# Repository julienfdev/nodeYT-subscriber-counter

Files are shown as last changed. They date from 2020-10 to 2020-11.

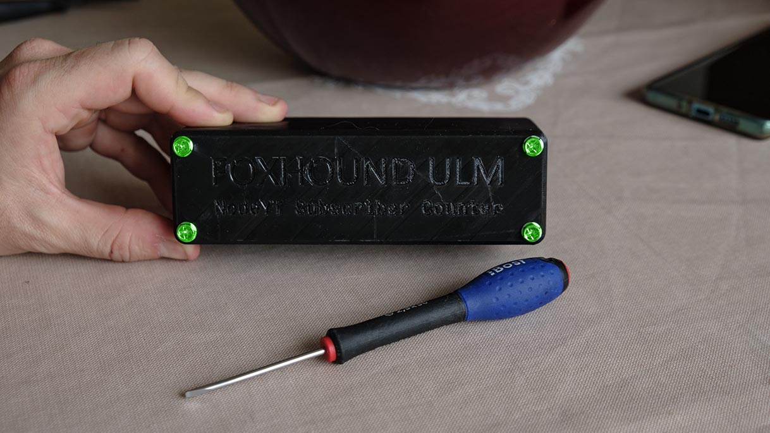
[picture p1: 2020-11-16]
img/howto-5.05f7cd65.jpg

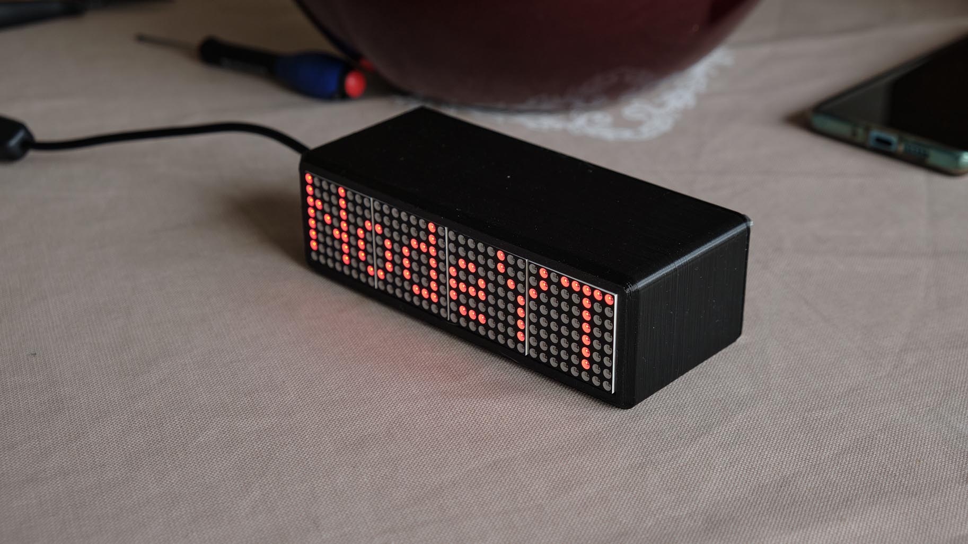
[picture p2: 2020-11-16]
img/howto-6.be0a37dc.jpg

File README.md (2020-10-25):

# NodeYT Subscriber Counter
## ESP8266 Version
A cheap ESP8266 - NodeMCU v3 subscriber counter - CC BY 4.0

See branch arduino-rpi for the Arduino / Raspberry Pi version (not maintained)

## Overview

The Node YT Subscriber Counter is a small and cheap LED Matrix YouTube counter based on a nodeMCU board (ESP8266) and a 8x32 MAX7219 LED Matrix.
As the name suggests... it counts YouTube subscribers

 ## Bill Of Material

### Mandatory
 - NodeMCU V3 ESP8266 Developement board - __7.79€__ https://amzn.to/31ySlPQ
 - 8x32 MAX7219 LED Matrix - __9.99€__ https://amzn.to/2HclQzS 
 - Arduino IDE 1.8+

### Optional
 - A 3D printer to print the case
 - 8x H5x6mm hex posts
 - 8x M3x8mm Socket Head Cap Screws
 - 4x 3.2x5mm Hex or Phillips screws (backplate fixation)
 - 5x 2.54mm (0.1" in Yankee units) male pin headers

__*Total BOM : 17.8€ + enclosure*__

## ESP8266 Configuration 

### Configuration and Upload
 - Clone the repository
 - Create a config.h file in ./esp8266, as following :

        #define MODE_SUBSCRIBERS 0

        String apiKey = "YOUR_YOUTUBE_API_KEY";
        String channelId = "YOUR_YOUTUBE_CHANNEL_ID";
        String ssid = "WIFI_SSID_TO_CONNECT_TO";
        String wifiPass = "WPA||WPA2__KEY";
        long refreshMillis = ;            // Refresh time in milliseconds
        int timezone = ; // Your Timezone eg : 1 for GMT+1 and -7 for GMT-7
        const char trustRoot[] PROGMEM = R"EOF(
                -----BEGIN CERTIFICATE-----
                THE_GOOGLE_API_CERTIFICATE
                -----END CERTIFICATE-----
                )EOF";
        // Caution, you must begin and end the String with R"EOF( )EOF" as shown;
        // To find the valid certificate just fetch anything at https://www.googleapis.com/ and click the lock next to the URL
        // Take the X509 Certificate and not SHA1 or SHA256 signature as they expires eventually

        String apiCall = String("https://www.googleapis.com/youtube/v3/channels?part=statistics&id=" + channelId + "&key=" + apiKey);

- Open the Arduino IDE and add the following source to the Additionnal Board Manager (Preferences)

        https://arduino.esp8266.com/stable/package_esp8266com_index.json

- Install the ESP8266 boards with the Board Manager
- Install the following libraries : 

        ArduinoJson // by Benoit Blanchon
        MD_Parola

- Select NodeMCU 1.0 and keep the default settings
- Open and upload the sketch to the board

### Remarks / Misc

__Boot sequence__

The NodeYT counter go through the following boot sequence : 
- Prints nodeYT during WiFi connection
- Synchronizes to NTP servers
- Prints the current local Time
- Fetches and print the subscriber count

__Serial debugger__

The ESP8266 opens a Serial at 115200 bauds, it sends various debug data :

- WiFi IP address
- Start / Response of HTTPS GET requests
- Current subscriber count or "same sub count" message
- Errors (to be improved)

Current soft watchdog implemementation assumes the animateDisplay() always eventually sends a true at the end of an animation. 

### Errors codes

Even if the serial provides detailed information about what's going on, one would find interesting to quick diagnose any problems. The displays thus prints various error codes depending on the issue : 

__WiFi related error codes__

- SSID : The SSID in config.h can't be reached
- Passwd : Wrong WPA||WPA2 Passkey

__API Related error codes__

- "HTTPS" : Can't establish https tunnel (verify your X509 certificate)
- "APIKey" : Bad Request code received from the YT API, most likely related to a bad API Private key
- "channel" : No channel exists with the ID provided in config.h
- err"xxx" : Generic error handler, displays the response code from the server

### WIP

- Clock Mode?
- Mode pushbutton (views-subs-clock)
- LED intensity potentiometer

## 3D printed case

### Hardware modifications :

A single mod needs to be done to the LED Matrix in order to fit into the RTM case (no mod if you're using the prototype one, but it's not advised as the RTM model is daaaamn slicker).

- Desolder the angled pin headers
- Solder the straight pin headers back, facing the side without any components (duh)

### Provided Files

The STL and Cura files provided assume a 20x123.5mm fixation pattern for the 8x32 LED Matrix

Disclamer about the prototype CATIA files : they are absolute shit as it's a revamp from the RPI+Arduino version.
RTM should be cleaner ^^

### Printing

Printing at 200/60°C with Geetech black PLA, 0.24mm layer height, tree support and faceplate ironing yields great results on an Ender3.

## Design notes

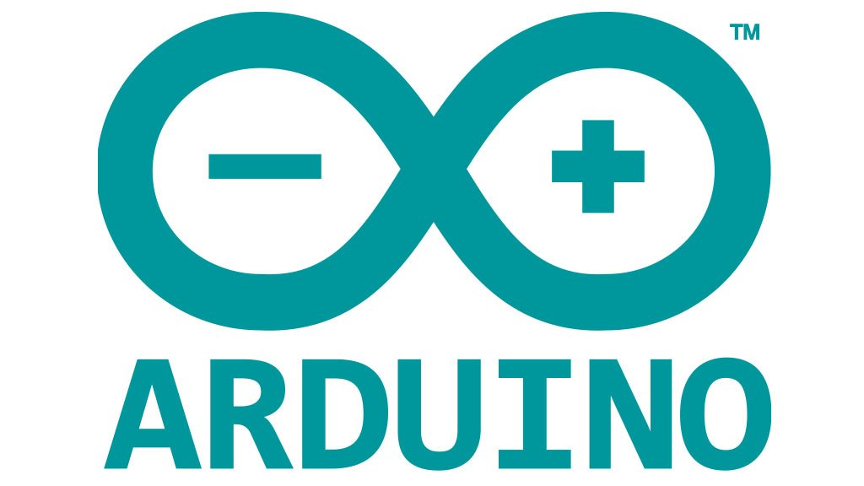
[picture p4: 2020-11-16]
img/card-0.86d80428.jpg

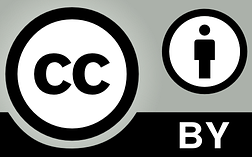
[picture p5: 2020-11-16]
img/cc-by.729ac44f.png

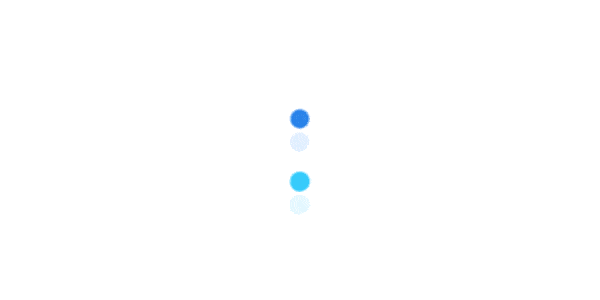
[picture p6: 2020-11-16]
img/spinner.845b3c8d.gif

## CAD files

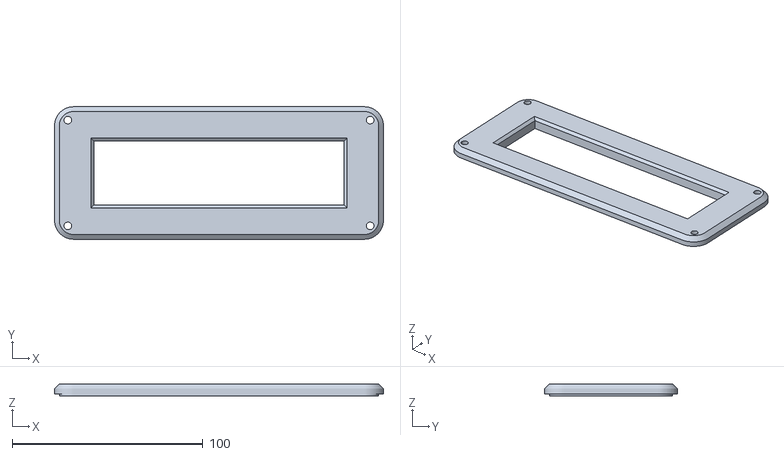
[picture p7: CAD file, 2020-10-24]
case/cura/stl/prototype/faceplate.stl
172.3 x 69.4 x 6.40

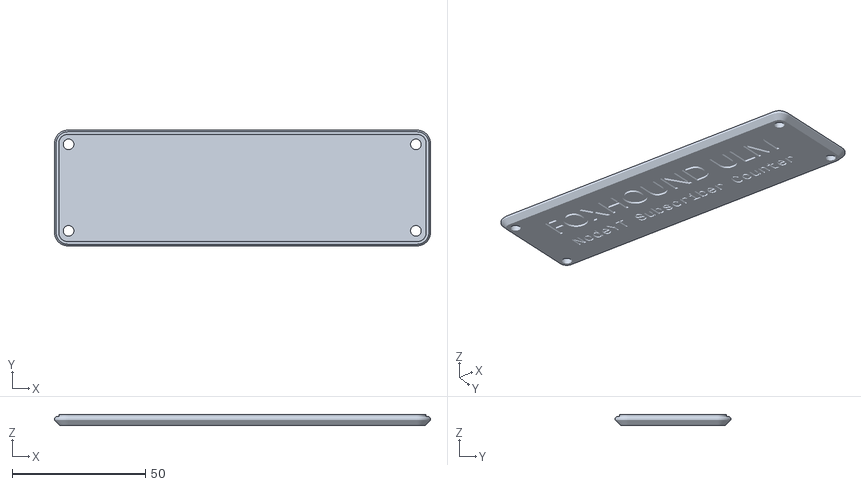
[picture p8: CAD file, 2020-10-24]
case/cura/stl/rtm/v2-backplate.stl
141.3 x 43.5 x 4.00

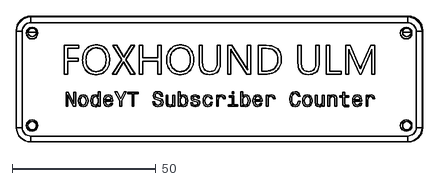
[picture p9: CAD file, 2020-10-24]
case/native/marking.dxf
141.5 x 43.8

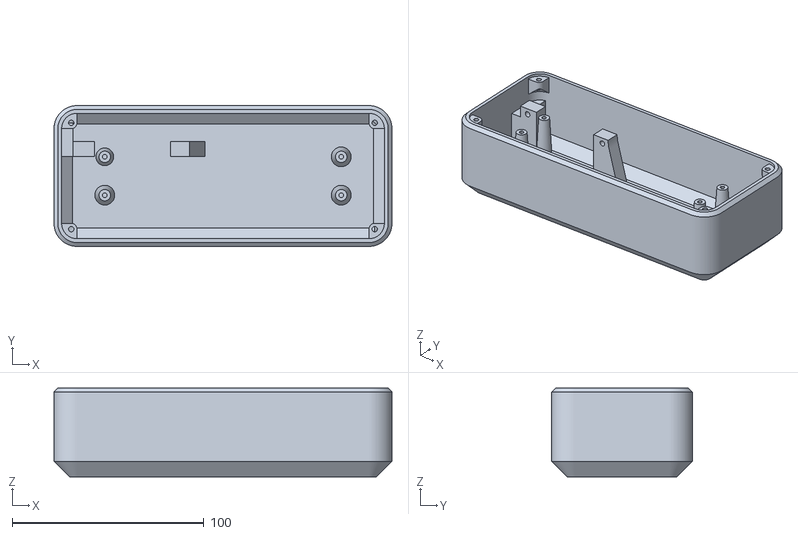
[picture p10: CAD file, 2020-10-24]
case/cura/stl/prototype/back-elmt.stl
176.3 x 73.4 x 46.2

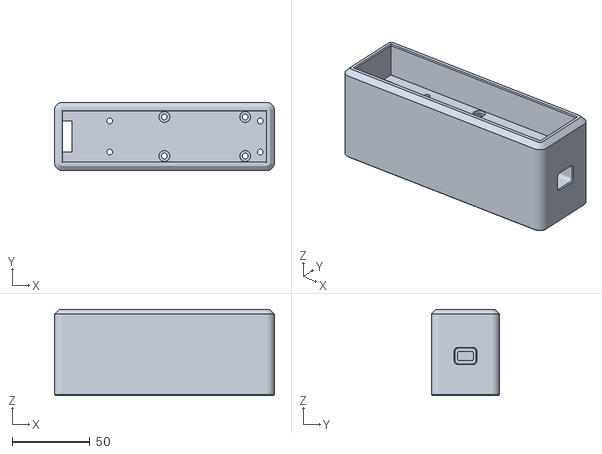
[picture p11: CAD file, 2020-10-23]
case/cura/stl/rtm/v2-case.stl
141.5 x 43.8 x 55.5

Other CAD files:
case/native/Part1.CATPart
case/native/backplate.CATPart
case/native/case-v2.CATPart
case/native/faceplate.CATPart
case/native/nodeYT-case.CATProduct

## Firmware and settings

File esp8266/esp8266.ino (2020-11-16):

// Networking
#include <ArduinoJson.h>
#include <ESP8266WiFi.h>
#include <ESP8266HTTPClient.h>
#include <WiFiClientSecureBearSSL.h>

// LED Matrix
#include <MD_Parola.h>
#include <MD_MAX72xx.h>
#include <SPI.h>
#define HARDWARE_TYPE MD_MAX72XX::FC16_HW
//#define MAX_DEVICES 1    //DEBUG
#define MAX_DEVICES 4
#define CLK_PIN   D5 // or SCK
#define DATA_PIN  D7 // or MOSI
#define CS_PIN    D8 // or SS

// Initializing the LED Matrix object with hardware SPI
MD_Parola P = MD_Parola(HARDWARE_TYPE, CS_PIN, MAX_DEVICES);

#include "config.h"

/*
   GLOBAL VARIABLES
*/
long subscriberCount = 0;
byte displayMode = MODE_SUBSCRIBERS;

// Creating an X509 Certificate based on the trustRoot signature in config.h
X509List cert(trustRoot);

// Creating the JSON Document Placeholder
const size_t capacity = JSON_ARRAY_SIZE(1) + JSON_OBJECT_SIZE(1) + 2 * JSON_OBJECT_SIZE(4) + JSON_OBJECT_SIZE(5) + 300;
DynamicJsonDocument doc(capacity);

void setup() {

  // Serial debugger
  Serial.begin(115200);
  Serial.println();

  // Setting up the display
  P.begin();
  P.setIntensity(1);
  P.setTextAlignment(PA_RIGHT);
  // Printing the welcome text
  P.displayText("NodeYT", PA_RIGHT, 50, 50, PA_SCROLL_RIGHT);
  // While the animation isn't finished
  while (!P.displayAnimate()) {
    ESP.wdtFeed(); // Feeding the Watchdog to avoid soft reset
  }


  // Initializing WiFi with SSID and provided in config file
  WiFi.begin(ssid, wifiPass);

  // Looping while not connected, need to be perfected to take errors into account ant print them
  while (WiFi.status() != WL_CONNECTED)
  {
    delay(500);
    Serial.print(".");
    wifiErrorHandler();
  }
  Serial.println();

  Serial.print("Connected, IP address: ");
  Serial.println(WiFi.localIP());
  Serial.println("");

  // Synchronising Time (GMT+1)
  configTime(timezone * 3600, 0, "pool.ntp.org", "time.nist.gov");
  // DST function to be done and recalled

  Serial.print("Waiting for NTP time sync: ");
  time_t now = time(nullptr);
  while (now < 8 * 3600 * 2) {
    delay(500);
    Serial.print(".");
    now = time(nullptr);
  }
  Serial.println("");
  struct tm timeinfo;
  struct tm timeLocal;
  gmtime_r(&now, &timeinfo);
  localtime_r(&now, &timeLocal);
  Serial.print("Zulu Time: ");
  Serial.print(asctime(&timeinfo));
  Serial.print("Local Time :");
  Serial.print(asctime(&timeLocal));

  // Printing local Time (DST to be implemented)
  String minutes = String(String(timeLocal.tm_min));
  Serial.println(minutes.length());
  if (!(minutes.length() > 1)) {
    minutes = String("0" + minutes);
  }
  String timeString = String(String("") + timeLocal.tm_hour + ":" + minutes);
  wipeScreen();
  printSubroutine(String("Clock:  "), PA_CENTER, PA_SCROLL_LEFT);
  printSubroutine(timeString, PA_CENTER, PA_SCROLL_LEFT);
  // Print the clock during 5 seconds
  delay(5000);

  // Wiping screen before getting subscriber count
  wipeScreen();
}


void loop() {
  if (displayMode == MODE_SUBSCRIBERS) {
    printHandler(getSubscriberCount());
    delay(refreshMillis); // To be changed to millis() comparison subroutine
  }
  // TBI : Mode change handler
}

String getSubscriberCount() {
  String payload = performApiCall();
  if (payload.startsWith("error-")) {
    return payload;
  }
  else {
    String subscriberFetch = extractSubscriberString(payload);
    return subscriberFetch;
  }
}

String performApiCall() {
  // Instancing a SSL Client
  BearSSL::WiFiClientSecure client;
  //
  //client.setTrustAnchors(&cert);
  // Uncomment following if you've got issues validating the cert (should be okay)
  client.setInsecure();

  // Creating an HTTPClient to perform the requests
  HTTPClient https;

  // We initiate a connection using the SSL client, to the apiCall string concatened from config variables
  Serial.print("[HTTPS] begin...\n");
  if (https.begin(client, apiCall)) {  // HTTPS

    Serial.print("[HTTPS] GET...\n");
    // start connection and send HTTP header
    int httpCode = https.GET();

    // httpCode will be negative on error
    if (httpCode > 0) {
      // HTTP header has been send and Server response header has been handled
      Serial.printf("[HTTPS] GET... code: %d\n", httpCode);

      // if we get a 200
      if (httpCode == HTTP_CODE_OK || httpCode == HTTP_CODE_MOVED_PERMANENTLY) {
        String payload = https.getString();
        return payload;
      }
      else if (httpCode == 400) {
        Serial.println("Bad Request - Most likely Bad API Key");
        return "error-APIKey";
      }
      else {
        Serial.printf("[HTTPS] GET... failed, error: %d\n", httpCode);
        subscriberCount = 0;
        return String("error-err" + String(httpCode));
      }
    } else {
      Serial.printf("[HTTPS] GET... failed, error: %d\n", httpCode);
      subscriberCount = 0;
      return String("error-err" + String(httpCode));

    }

    https.end();
  } else {
    Serial.printf("[HTTPS] Unable to connect\n");
    return "error-HTTPS";
  }
}

void printHandler(String rawCount) {
  // Every payload starting with "error-" will be handled as errors
  if (rawCount.startsWith("error-")) {
    String errorCode = rawCount.substring(6);
    printSubroutine(errorCode, PA_RIGHT, PA_SCROLL_RIGHT);
  }
  else {
    long fetchedSubCountInteger = rawCount.toInt();
    if (fetchedSubCountInteger != subscriberCount ) {
      subscriberCount = fetchedSubCountInteger; // COMMENT FOR DEBUG
      Serial.printf("Subscriber count is : %d\n", fetchedSubCountInteger);
      String formattedString = formatSubscriberCount(subscriberCount); // Formatting function
      printSubroutine(formattedString, PA_RIGHT, PA_SCROLL_RIGHT); //Display function
    }
    else {
      Serial.println("Same subscriber count - skipping");
    }
  }
}

void printSubroutine(String stringToPrint, textPosition_t textAlignment, textEffect_t effectDirection) {
  P.displayText(stringToPrint.c_str(), textAlignment, 50, 50, effectDirection);
  P.displayReset();
  while (!P.displayAnimate()) {
    ESP.wdtFeed(); // Feeding the Watchdog to avoid soft reset
  }
} // While the animation isn't finished

void wipeScreen() {
  P.displayText(" ", PA_RIGHT, 50, 50, PA_SCROLL_RIGHT);
  P.displayReset();
  while (!P.displayAnimate()) {
    ESP.wdtFeed(); // Feeding the Watchdog to avoid soft reset
  }
}

String formatSubscriberCount(long subscriberCount) {
  if (subscriberCount < 1000) {
    return String(subscriberCount);
  }
  else if (subscriberCount < 10000) {
    // example 1337, want 1.37k, need to perform round operation from 133.7 --> 134
    double floatBuffer = ((double)subscriberCount / (double)10.);
    double roundedValue = round(floatBuffer); // 134
    roundedValue = roundedValue / (double)100.; // 1.3400000
    String numericPart = String(roundedValue, 2); // "1.34"

    return String(numericPart + "k");
  }
  else if (subscriberCount < 100000) {
    // example 85625, want 85.6k, need to perform round operation from 856.2 --> 856
    double floatBuffer = ((double)subscriberCount / (double)100.);
    double roundedValue = round(floatBuffer); // 856
    roundedValue = roundedValue / (double)10.; // 85.600000000000
    String numericPart = String(roundedValue, 1); // "85.6"

    return String(numericPart + "k");
  }
  else if (subscriberCount < 1000000) {
    // example 856256, want 856k, need to perform round operation from 856.2 --> 856
    double floatBuffer = ((double)subscriberCount / (double)1000.);
    double roundedValue = round(floatBuffer); // 856
    String numericPart = String(roundedValue, 0); // "856"

    return String(numericPart + "k");
  }
  else if (subscriberCount < 10000000) {
    // example 8 562 560, want 8,56m, need to perform round operation from 856.2 --> 856
    double floatBuffer = ((double)subscriberCount / (double)10000.);
    double roundedValue = round(floatBuffer); // 856
    roundedValue = roundedValue / (double)100.; // 8.56000000
    String numericPart = String(roundedValue, 2); // "8.56"

    return String(numericPart + "M");
  }

}

String extractSubscriberString(String payload) {
  // Breaking down Json into objects
  deserializeJson(doc, payload);

  // Error handling
  int resultsPerPage = doc["pageInfo"]["resultsPerPage"];
  if (resultsPerPage == 0) {
    return "error-channel";
  }
  else {
    JsonObject items = doc["items"][0];
    JsonObject stats = items["statistics"];
    String subscriberCount = stats["subscriberCount"];

    return String(subscriberCount);
  }

}

/*
   Checks the WiFi connection status and print Error accordingly
*/
void wifiErrorHandler() {
  if (WiFi.status() == WL_NO_SSID_AVAIL) {
    Serial.println("SSID Unreachable - Sleeping 30s");
    wipeScreen();
    printHandler("error-SSID");
    delay(30000);
  }
  else if (WiFi.status() == WL_CONNECT_FAILED) {
    Serial.println("Wrong WiFi passkey - Sleeping 30s");
    wipeScreen();
    printHandler("error-Passwd");
    delay(30000);
  }
}

// Takes a dateTime and checks for the date (Europe DST)
bool daylightSavingChecker(tm dateTime) {

}

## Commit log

2020-10-22 NodeYT ESP8266 version
    [back-elmt.stl, faceplate.CATPart, faceplate.stl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]
2020-10-23 updated case STL, Cura and native files
    [CE3_back-elmt.3mf, back-elmt.stl, faceplate.CATPart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]
2020-10-23 error handling + mode definitions
    [esp8266.ino]
2020-10-23 case v2 - compact
    [Part1.CATPart, backplate.CATPart, case-v2.CATPart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]
2020-10-24 marking - RTM case
    [CE3_back-elmt.3mf, back-elmt.stl, backplate.CATPart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]
